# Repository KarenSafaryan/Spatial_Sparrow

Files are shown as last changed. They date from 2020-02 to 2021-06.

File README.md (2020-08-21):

# SpatialSparrow

Multimodal rate discriminaton behavioral task for mice.

## Description of the setup

This should show a labeled picture of the setup. 

## Data saving and automatic copy

This should say what gets saved where and what is automatically copied and when. 

The TouchShaker teensy module reports lick and handle touch times, these get communicated and logged by Bpod.

### SessionData.RawEvents

Event list correspondence :

| TouchShaker byte | Event |
|---|---|
| TouchShaker1_1 | left_spout_touch |
| TouchShaker1_2 | right_spout_touch |
| TouchShaker1_3 | left_spout_release |
| TouchShaker1_4 | right_spout_release |
| TouchShaker1_5 | left_handle_touch |
| TouchShaker1_6 | right_handle_touch |
| TouchShaker1_7 | both_handle_touch |
| TouchShaker1_8 | left_handle_release |
| TouchShaker1_9 | right_handle_release |
| TouchShaker1_14 | acknowledge |
| TouchShaker1_15 | error |

State list correspondence:

## Settings and description

Settings can be set from Bpod (mat files in Bpod Local/Settings).
Default settings are in SpatialSparrow.m

Settings for `training control`:

| Setting | Default | Description |
|---|---|---|
| SubjectName | | Name of the mouse |
| RewardedModality | AudioVisual |'Vision', 'Audio', Somatossensory, 'AudioVisual', 'Mixed' |
| leftRewardVolume | 2 ul | Amount of water per left reward |
| rightRewardVolume | 2 ul | Amount of water per right reward |
| AutoReward | OFF | Pre-load rewarded spout |
| TrainingMode | OFF | Move spouts to the correct side |
| autoRewardVision | 1 | Fraction of self-performed trials (Vision) |
| autoRewardAudio | 1 | Fraction of self-performed trials (Auditory) |
| autoRewardPiezo | 1 | Fraction of self-performed trials (Somatossensory) |
| autoRewardMixed | 1 | Fraction of self-performed trials (Mixed) |
| LeverSound | true | Play a sound when the mouse touches the handles |
| RegularStim | false | Produce regular stimuli sequences |
| biasSeqLength | 3 | nr of trials on one side after which the oposite side is switched with 50% probability |

Settings for `trial timing` :

| Setting | Default | Description |
|---|---|---|
| preStimDelay | 1 (s) | time on handle before stimuli presentation |
| StimDuration | 1 (s) | duration of the stimulus |
| happyTime | 0.5 (s) | duration of the last state (gives time to collect reward) |
| varStimDur | 0 (s) | variable stim duration (StimDuration + varStimDur) is the actual stim duration |
| optoDur | 0.5 (s) | duration of the optogenetics stimuli |
| optoRmp | 0.2 (s) | duration of the optogenetics ramp down (optoDur = 0.5 and optoRamp = 0.2 makes a 500ms stimulus that ramps down after 300ms) ??????? |
| minITI | 1 (s) | min inter trial interval (additional) |
| maxITI | 2 (s) | max inter trial interval (additional) |
| ITIlambda | 10 (AU) | bariability between minITI and maxITI. High lambda -> closer to minITI |
| WaitingTime | 1 (s) | minimum waiting time before a response can be made, early licks are ignored |
| TimeToChoose | 3 (s) | how long to wait for choice report |
| TimeToConfirm | 0.5 (s) | how long to wait for a 2nd (confirmation) lick |
| Timeout | 3 (s) | timeout to punish wrong responses |
| LeverWait | 10 (s) | time to wait for handle grasp |
| MoveLever | TRUE | move levers or not (set to FALSE during habituation)|
| UseBothLevers | FALSE | Whether both handles need to be touched to initiate trials |
| WaitBeforeLever | 1 (s) | Wait time before handles are moved in after trial onset|

Settings for `stimuli parameters` :

| Setting | Default | Description |
|---|---|---|
| TargRate  | 10 (Hz) | Rate of the target sequence |
| ProbRight  | 0.5 | Fraction of targets on the right |
| DistFractions  | 0  | Distractor pulses (fraction of the target sequence). Can be a scalar [0-1] or a vector |
| DistProb  | 0  | Probability of presenting a distractor |
| TestModality  | 0  | Modality to be used with discrimination (1=vis, 2=aud, 4=ss). Zero is inactive. Other values are detection only |
| BinSize  | 50 (ms) | Stimuli refractory period (min interval between pulses) |
| StimCoherence  | TRUE | Determines whether multisensory stimuli are correlated | 
| UseNoise  | FALSE | Use noise burst (TRUE) of clicks (FALSE) as auditory stimuli |
| varStimOn  | [0 0.125 0.25] (s) | Variable onset time for stimulus after lever grab in s. This can be a vector of values. Have to be 0 and higher. |
| StimGap  | 0 (s) | Duration of the gap in the middle of stimulus presentation in s; if >0 the stim duration is of stimDuration*2 + stimGap long |
| DecisionGap  | [0.3 1.5] (s) | Range of the interval between the stimulus and the decision period |
| BeepDuration  | 20 (ms) | Beep (auditory) duration |
| StimLoudness  | 0.5 | Strength of auditory stimuli |
| FlashDuration  | 20 (ms) | Flash (visual) duration |
| StimBrightness  | 20  | Brightness of flashes. Multiplier of the base frequency, default is 100Hz (????) |
| BuzzDuration  | 20 (ms) | Buzz (somatossensory) duration |
| BuzzStrength  | 1  | Strength of buzzes |
| ProbAudio  | 0  | Probability of presenting an auditory-only trial (for multimodal) |
| ProbVisual  | 0  | Probability of presenting a visual-only trial (for multimodal) |
| ProbPiezo  | 0  | Probability of presenting a somatossensory-only trial (for multimodal) |
| sRate  | 20000  | Sampling rate of the AnalogOutput module |
| PunishSoundDur  | 0 (s)  | Duration of the white noise punishment sound |
| optoProb  | 0  | Fraction of optogenetics trials |
| optoTimes  | Stimulus/Delay | Part of the trial where optogenetic stimulus should be presented |
| optoRight  | 0.5  | Probability for occurence of an optogenetic stimulus on the right |
| optoBoth  | 1  | Probability for occurence of an optogenetic stimulus on both sides. This comes after determining a single HS target ??? |
| optoPower  | 5  | Fraction of optogenetics stimuli |

Settings for `hardware control and sync` :

| Setting | Default | Description |
|---|---|---|
| SpoutSpeed | 25 (ms) | Duration of spout movement |
| rMaxSpoutIn | 30 | Right spout inner position (value between 0 and 100) |
| lMaxSpoutIn | 30 | Left spout outer position (value between 0 and 100) |
| spoutOffset | 10 | Distance from inner spout position |
| lOuterLim | 3.5 | Left spout outer position (value between 0 and 100) |
| LeverSpeed | 150 (ms) | Duration of handle movement (ms) |
| LeverIn | 20 | Inner position of the handles |
| LeverOut | 0 | Position of handle out of reach |
| TouchThresh| 5 (SDUs) | Threshold for capacitive touch lines |
| WaitForCam  | false  | Trials wait for a camera trigger to start. |

To check: rInnerLim, lInnerLim, rOuterLim, lOuterLim

Settings for `paths and data copy` :
| Setting | Default | Description |
|---|---|---|
| widefieldPath | ... | path to widefield data on server |
| serverPath |  ... | path to behavioral data on server |
| videoDrive | C: | path to behavioral data on server |
| bonsaiEXE | ... | path to bonsai.exe  |
| bonsaiParadim | ... | path to the bonsai workflow ('' to skip bonsai)  |
| labcamsAddress | localhost:9999 | address to connect to labcams for video acquisition (leave empty to skip) |
| wavePort | COM18 | COM port of the AnalogOutput Module |

`Plot` settings:
| Variable | Default | Description |
|---|---|---|
| PerformanceSwitch| Performed | Show performance over all trials or only self-performed trials |
| DoFit| false | Show curve fitting in the performance plot |
| modSelector| Combined | Which data to show in the performance plot |

Operational variables:
| Variable | Default | Description |
|---|---|---|
| SaveSettings | false | Saves the current settings |
| AdjustSpouts | 0 | Pause for spout adjustment |
| StartTime | ? | Start time of the current session |
| cTrial |  | Number of the current trial |
| runTime |  | Duration of the current session |
| servoPos | [0 0] | position of left and right spout, relative to their inner limit. these values will be changed by anti-bias correction to correct spout position |

## Instalation and build instructions

Clone the repository to Bpod Local/Protocols. If you make changes; create a branch and remember to commit changes regularly.

Build instructions coming here soon.

### Video

There are 2 options for recording video with SpatialSparrow: using [Bonsai](https://bonsai-rx.org/introduction) or using [labcams](https://bitbucket.org/jpcouto/labcams). This readme should show you how to sync the cameras to the BPod (work in progress).

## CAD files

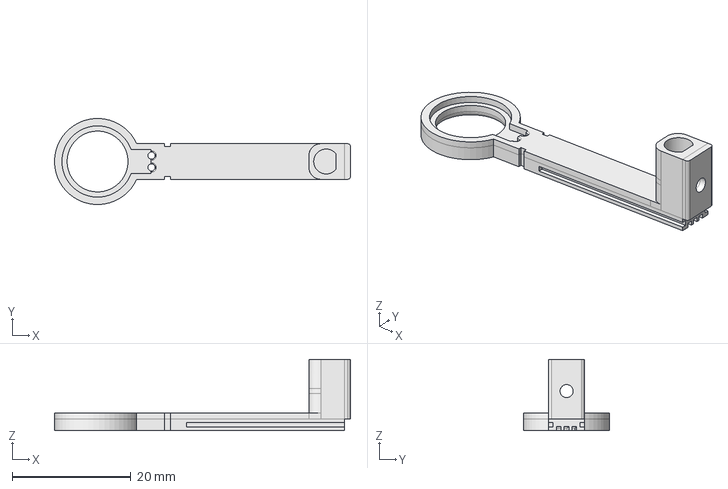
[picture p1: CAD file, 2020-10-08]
parts/freecad/handle_stepper.FCStd
49.9 x 14.5 x 12.0 mm

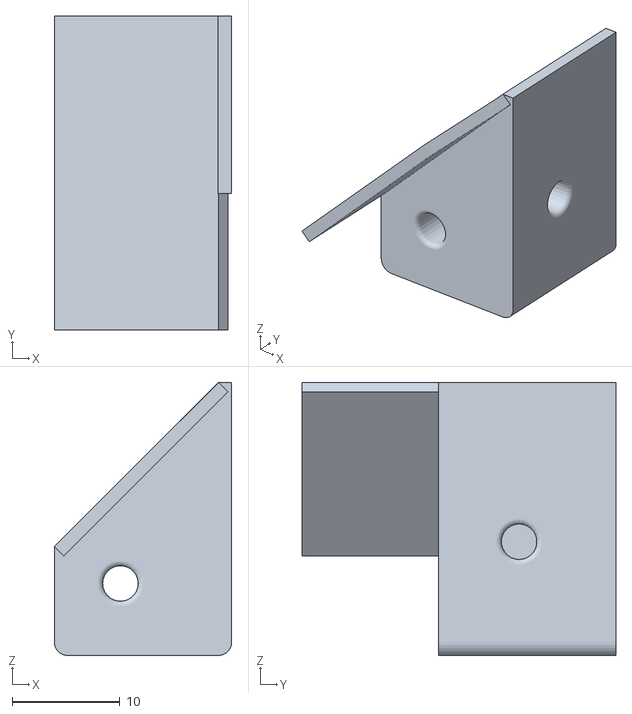
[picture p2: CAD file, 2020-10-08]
parts/stl/01_mirror_holder_45.stl
16.5 x 29.2 x 25.4

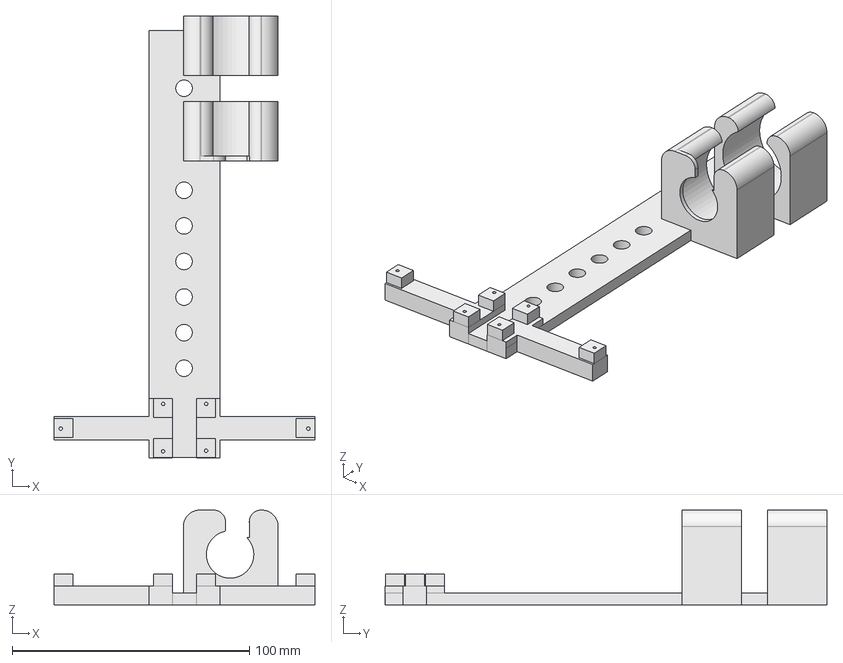
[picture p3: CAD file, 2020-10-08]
parts/freecad/water_valves_external.FCStd
110.0 x 186.1 x 40.0 mm

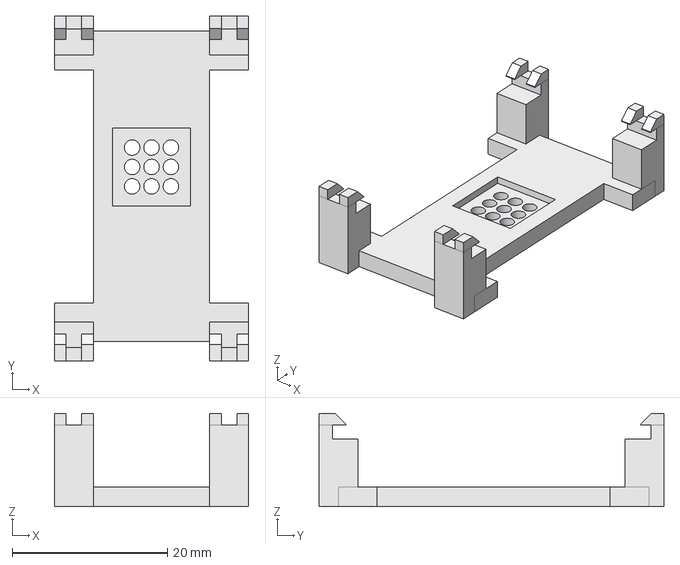
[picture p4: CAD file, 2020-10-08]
parts/freecad/LED_panel_holder.FCStd
25.0 x 44.4 x 12.0 mm

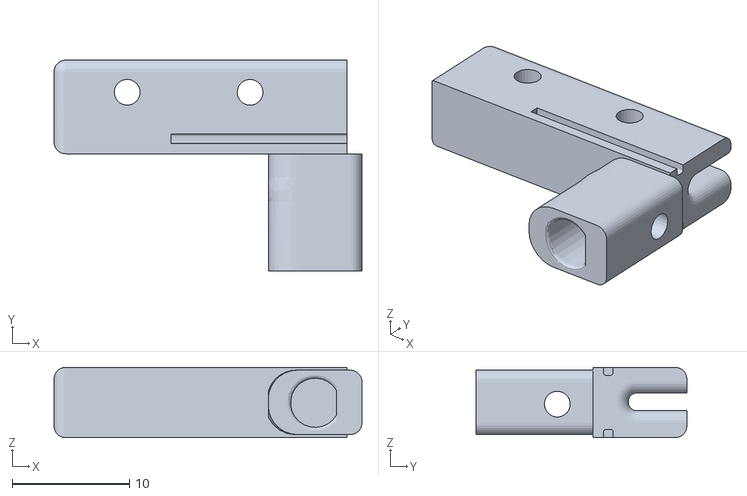
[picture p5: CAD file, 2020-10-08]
parts/stl/02_spout_holder.stl
26.3 x 18.0 x 6.00

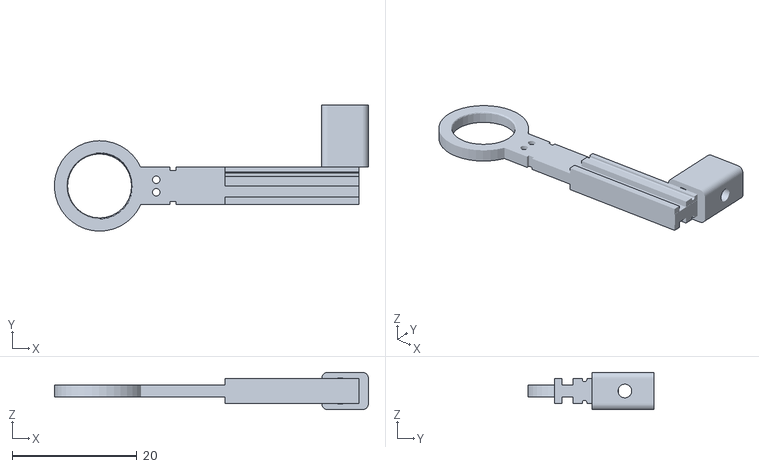
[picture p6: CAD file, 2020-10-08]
parts/stl/02_handle_rotated_flipped.stl
50.3 x 20.2 x 6.00

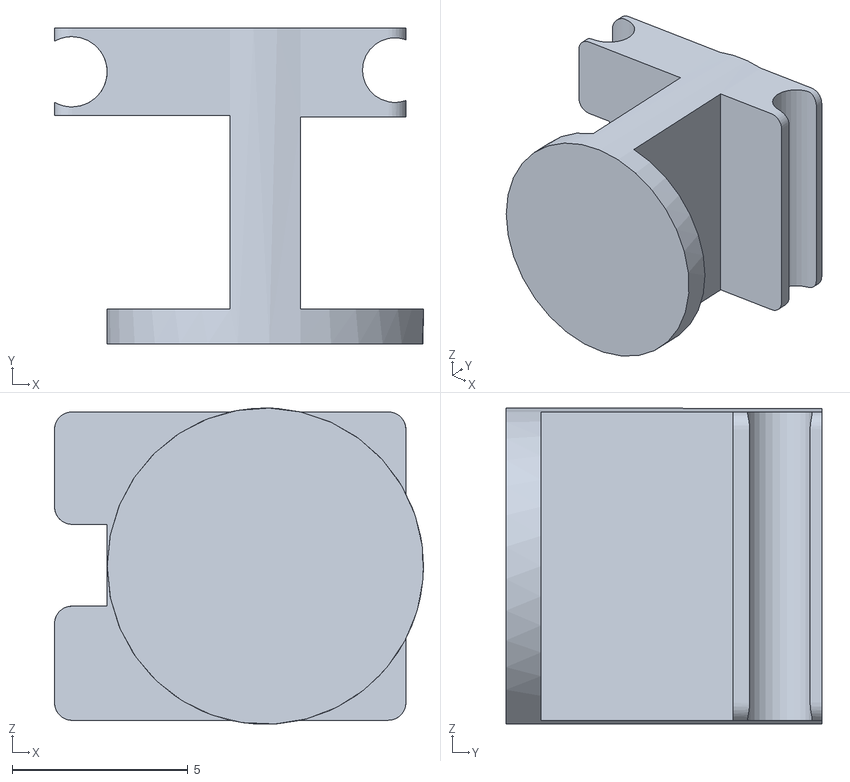
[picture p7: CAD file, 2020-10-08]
parts/stl/02_handle.stl
10.5 x 9.00 x 8.99

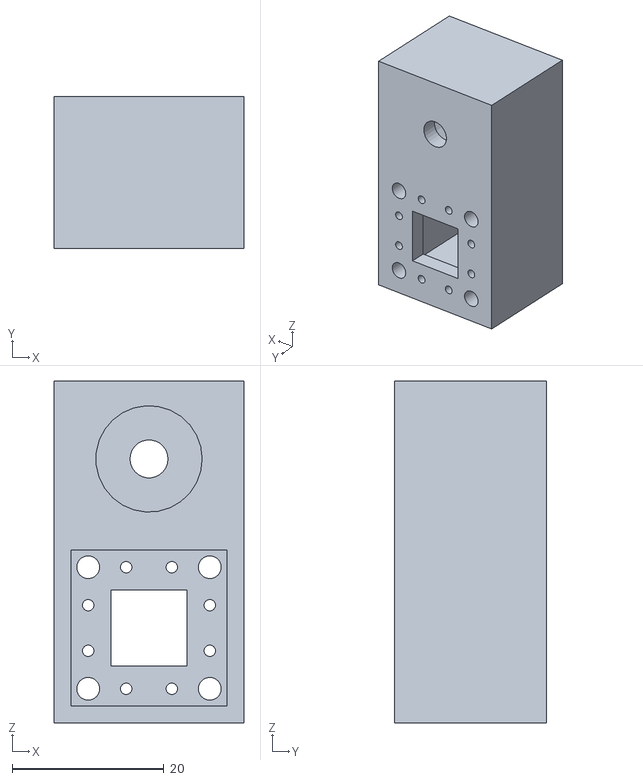
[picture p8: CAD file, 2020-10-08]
parts/stl/02_handle_stepper.stl
25.0 x 20.0 x 45.0

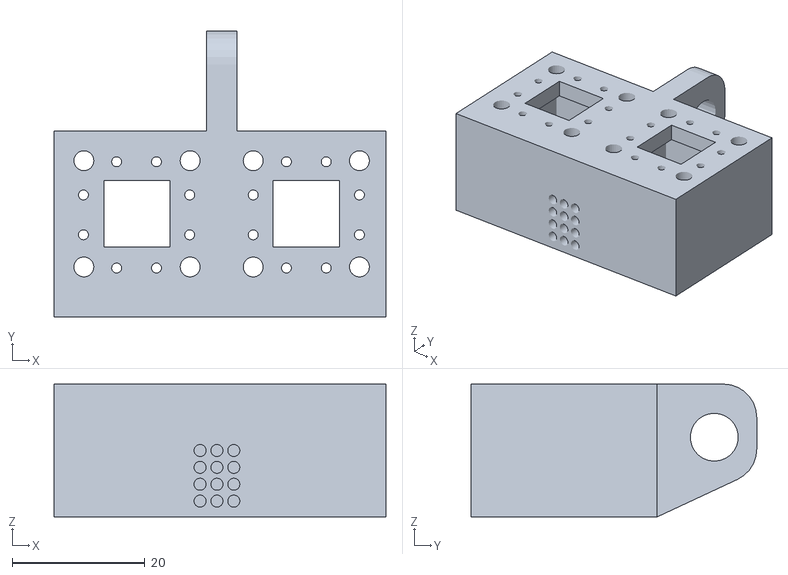
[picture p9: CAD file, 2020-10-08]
parts/stl/01_spout_steppers_holder.stl
50.0 x 43.0 x 20.0

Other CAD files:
parts/stl/01_water_valves_external.stl
parts/freecad/spout_holder.FCStd
parts/freecad/handle_stepper_flipped.FCStd
parts/stl/02_handle_holder.stl

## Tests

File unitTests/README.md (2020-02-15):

+++ Unit tests for the Spatial Sparrow behavioral paradigm

++++ Teensy

     - *Move stepper motor* - tests that the stepper motors are working

     - *Bar graph LED* - tests a teensy LED bar graph 

++++ MATLAB

     - *test_ao.m* - test the bpod analog output module

     - *test_steppers.m* - move and test the spouts and handles

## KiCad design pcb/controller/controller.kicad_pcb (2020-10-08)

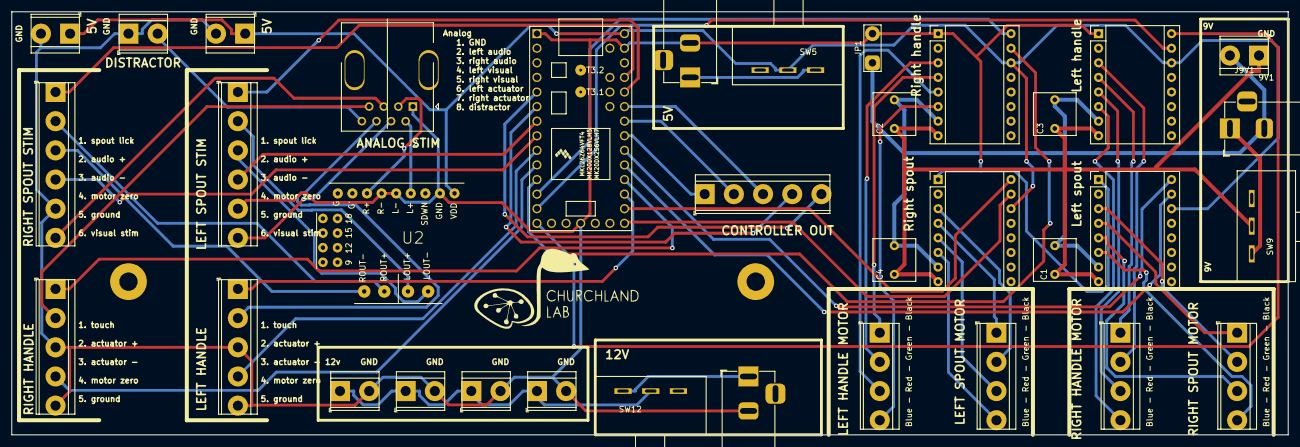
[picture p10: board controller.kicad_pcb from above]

Board: 2 copper layers, 222.2 x 73.7 mm, 37 parts (0 on the bottom side), 56 nets.

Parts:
5V1: 5V; BarrelJack_Horizontal
9V1: 9V; BarrelJack_Horizontal
12V1: 12V; BarrelJack_Horizontal
C1, C2, C3, C4: 100 uF; C_Rect_L7.2mm_W7.2mm_P5.00mm_FKS2_FKP2_MKS2_MKP2
HandleL-ToMotor1: Screw_Terminal_01x04; TerminalBlock_TE_282825-4_1x04_P5.08mm_Horizontal
HandleR-ToMotor1: Screw_Terminal_01x04; TerminalBlock_TE_282825-4_1x04_P5.08mm_Horizontal
J2: RJ45; RJ45_sparkfun
J5V1, J5V2, J9V1, J12V1, J12V2, J12V3, J12V4: Screw_Terminal_01x02; TerminalBlock_TE_282825-2_1x02_P5.08mm_Horizontal
JP1: gnd jumper; TestPoint_2Pads_Pitch5.08mm_Drill1.3mm
MC-LeverL1: Pololu_Breakout_DRV8825; Pololu_Breakout-16_15.2x20.3mm
MC-LeverR1: Pololu_Breakout_DRV8825; Pololu_Breakout-16_15.2x20.3mm
MC-SpoutL1: Pololu_Breakout_DRV8825; Pololu_Breakout-16_15.2x20.3mm
MC-SpoutR1: Pololu_Breakout_DRV8825; Pololu_Breakout-16_15.2x20.3mm
SW5: SW5V; SW_L102021ML04Q
SW9: SW9V; SW_L102021ML04Q
SW12: SW12V; SW_L102021ML04Q
SoundVisionL1: Screw_Terminal_01x06; TerminalBlock_TE_282825-6_1x06_P5.08mm_Horizontal
SoundVisionR1: Screw_Terminal_01x06; TerminalBlock_TE_282825-6_1x06_P5.08mm_Horizontal
SpoutL-ToMotor1: Screw_Terminal_01x04; TerminalBlock_TE_282825-4_1x04_P5.08mm_Horizontal
SpoutR-ToMotor1: Screw_Terminal_01x04; TerminalBlock_TE_282825-4_1x04_P5.08mm_Horizontal
ToHandleL1: Screw_Terminal_01x05; TerminalBlock_TE_282825-5_1x05_P5.08mm_Horizontal
ToHandleR1: Screw_Terminal_01x05; TerminalBlock_TE_282825-5_1x05_P5.08mm_Horizontal
U1: Teensy3.2; Teensy30_31_32_LC
U2: MAX98306
distractor1: Screw_Terminal_01x02; TerminalBlock_TE_282825-2_1x02_P5.08mm_Horizontal
mount1, mount2: MountingHole_3.2mm_M3_Pad
sync_trigger_out1: Screw_Terminal_01x05; TerminalBlock_TE_282825-5_1x05_P5.08mm_Horizontal

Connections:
+5V: J5V1.1, J5V2.1, MC-LeverL1.14, MC-LeverR1.14, MC-SpoutL1.14, MC-SpoutR1.14, SW5.2, U1.33, U2.1
+9V: C1.1, C2.1, C3.1, C4.1, J9V1.1, MC-LeverL1.8, MC-LeverR1.8, MC-SpoutL1.8, MC-SpoutR1.8, SW9.2
+12V: J12V1.1, J12V2.1, J12V3.1, J12V4.1, SW12.2
GND: 5V1.2, 12V1.2, J2.1, J5V1.2, J5V2.2, J12V1.2, J12V2.2, J12V3.2, J12V4.2, JP1.2, MC-LeverL1.1, MC-LeverR1.1, MC-SpoutL1.1, MC-SpoutR1.1, SoundVisionL1.5, SoundVisionR1.5, ToHandleL1.3, ToHandleL1.5, ToHandleR1.3, ToHandleR1.5, U1.1, U1.17, U1.32, U2.2, U2.5, U2.6, distractor1.1
GND1: 9V1.2, C1.2, C2.2, C3.2, C4.2, J9V1.2, JP1.1, MC-LeverL1.7, MC-LeverR1.7, MC-SpoutL1.7, MC-SpoutR1.7
unnamed: 5V1.1, SW5.1
unnamed: 9V1.1, SW9.1
unnamed: 12V1.1, SW12.1
unnamed: HandleL-ToMotor1.1, MC-LeverL1.4
unnamed: HandleL-ToMotor1.2, MC-LeverL1.3
unnamed: HandleL-ToMotor1.3, MC-LeverL1.5
unnamed: HandleL-ToMotor1.4, MC-LeverL1.6
unnamed: HandleR-ToMotor1.1, MC-LeverR1.4
unnamed: HandleR-ToMotor1.2, MC-LeverR1.3
unnamed: HandleR-ToMotor1.3, MC-LeverR1.5
unnamed: HandleR-ToMotor1.4, MC-LeverR1.6
unnamed: J2.2, U2.4
unnamed: J2.3, U2.7
unnamed: J2.4, SoundVisionL1.6
unnamed: J2.5, SoundVisionR1.6
unnamed: J2.6, ToHandleL1.2
unnamed: J2.7, ToHandleR1.2
unnamed: J2.8, distractor1.2
unnamed: MC-LeverL1.15, U1.11
unnamed: MC-LeverL1.16, U1.12
unnamed: MC-LeverR1.15, U1.13
unnamed: MC-LeverR1.16, U1.14
unnamed: MC-SpoutL1.3, SpoutL-ToMotor1.2
unnamed: MC-SpoutL1.4, SpoutL-ToMotor1.1
unnamed: MC-SpoutL1.5, SpoutL-ToMotor1.3
unnamed: MC-SpoutL1.6, SpoutL-ToMotor1.4
unnamed: MC-SpoutL1.15, U1.20
unnamed: MC-SpoutL1.16, U1.21
unnamed: MC-SpoutR1.3, SpoutR-ToMotor1.2
unnamed: MC-SpoutR1.4, SpoutR-ToMotor1.1
unnamed: MC-SpoutR1.5, SpoutR-ToMotor1.3
unnamed: MC-SpoutR1.6, SpoutR-ToMotor1.4
unnamed: MC-SpoutR1.15, U1.24
unnamed: MC-SpoutR1.16, U1.25
unnamed: SoundVisionL1.1, U1.29
unnamed: SoundVisionL1.2, U2.11
unnamed: SoundVisionL1.3, U2.10
unnamed: SoundVisionL1.4, U1.7
unnamed: SoundVisionR1.1, U1.30
unnamed: SoundVisionR1.2, U2.12
unnamed: SoundVisionR1.3, U2.13
unnamed: SoundVisionR1.4, U1.8
unnamed: ToHandleL1.1, U1.22
unnamed: ToHandleL1.4, U1.9
unnamed: ToHandleR1.1, U1.23
unnamed: ToHandleR1.4, U1.10
unnamed: U1.5, sync_trigger_out1.5
unnamed: U1.6, sync_trigger_out1.4
unnamed: U1.26, sync_trigger_out1.1
unnamed: U1.27, sync_trigger_out1.2
unnamed: U1.28, sync_trigger_out1.3

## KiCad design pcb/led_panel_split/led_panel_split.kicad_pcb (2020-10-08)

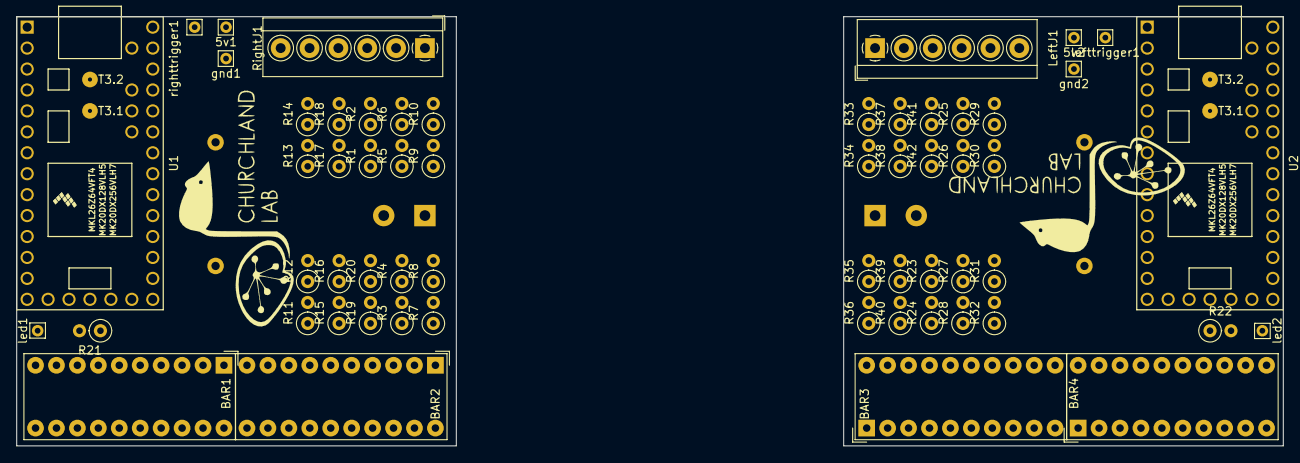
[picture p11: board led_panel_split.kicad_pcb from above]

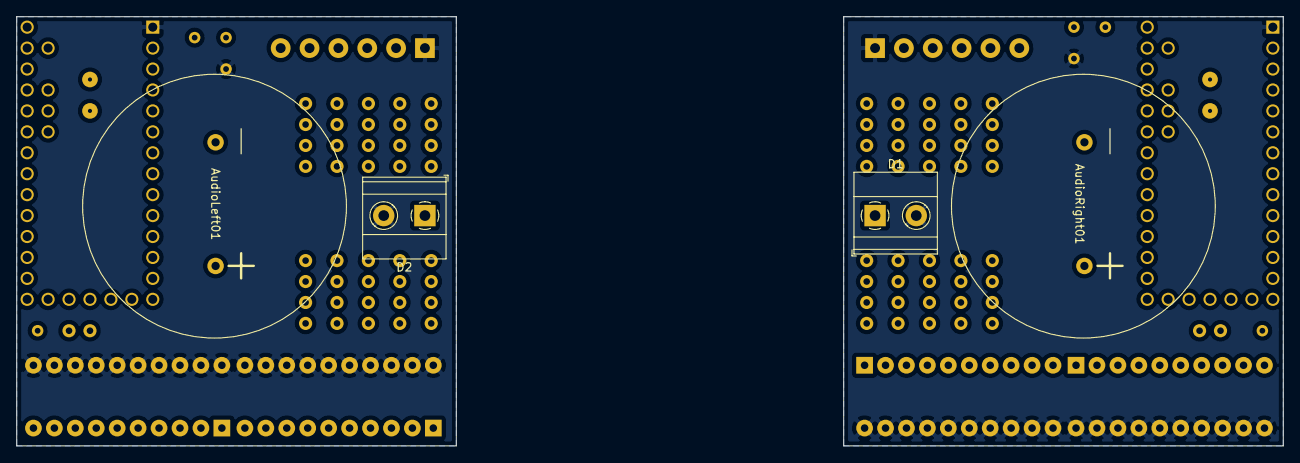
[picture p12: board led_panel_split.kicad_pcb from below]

Board: 2 copper layers, 153.7 x 52.1 mm, 64 parts (4 on the bottom side), 92 nets, no tracks yet.

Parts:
5v1, 5v2: 5V; Pin_D0.7mm_L6.5mm_W1.8mm_FlatFork
AudioLeft01: Audio left; speaker
AudioRight01: Audio right; speaker
BAR1, BAR2, BAR3, BAR4: HDSP-4830_2; HDSP-4830
D1, D2: LED; TerminalBlock_Phoenix_MKDS-1,5-2_1x02_P5.00mm_Horizontal
G1, G2: LOGO; churchland_lab_logo
LeftJ1: Left screw terminal; TerminalBlock_4Ucon_1x06_P3.50mm_Horizontal
R1, R2, R3, R4, R5, R6, R7, R8, R9, R10, R11, R12, R13, R14, R15, R16, R17, R18, R19, R20, R21, R22, R23, R24, R25, R26, R27, R28, R29, R30, R31, R32, R33, R34, R35, R36, R37, R38, R39, R40, R41, R42: R; R_Axial_DIN0207_L6.3mm_D2.5mm_P2.54mm_Vertical
RightJ1: Right screw terminal; TerminalBlock_4Ucon_1x06_P3.50mm_Horizontal
U1, U2: Teensy3.2; Teensy30_31_32_LC
gnd1, gnd2: GND; Pin_D0.7mm_L6.5mm_W1.8mm_FlatFork
led1: LED1 test; Pin_D0.7mm_L6.5mm_W1.8mm_FlatFork
led2: LED2 test; Pin_D0.7mm_L6.5mm_W1.8mm_FlatFork
lefttrigger1: left trigger; Pin_D0.7mm_L6.5mm_W1.8mm_FlatFork
righttrigger1: right trigger; Pin_D0.7mm_L6.5mm_W1.8mm_FlatFork

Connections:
+5V: 5v1.1, 5v2.1, LeftJ1.2, RightJ1.2, U1.33, U2.33
GND: BAR1.11, BAR1.12, BAR1.13, BAR1.14, BAR1.15, BAR1.16, BAR1.17, BAR1.18, BAR1.19, BAR1.20, BAR2.11, BAR2.12, BAR2.13, BAR2.14, BAR2.15, BAR2.16, BAR2.17, BAR2.18, BAR2.19, BAR2.20, BAR3.11, BAR3.12, BAR3.13, BAR3.14, BAR3.15, BAR3.16, BAR3.17, BAR3.18, BAR3.19, BAR3.20, BAR4.11, BAR4.12, BAR4.13, BAR4.14, BAR4.15, BAR4.16, BAR4.17, BAR4.18, BAR4.19, BAR4.20, D1.2, D2.2, LeftJ1.1, RightJ1.1, U1.1, U2.1, gnd1.1, gnd2.1
unnamed: AudioLeft01.1, LeftJ1.5
unnamed: AudioLeft01.2, LeftJ1.6
unnamed: AudioRight01.1, RightJ1.5
unnamed: AudioRight01.2, RightJ1.6
unnamed: BAR1.1, R20.2
unnamed: BAR1.2, R19.2
unnamed: BAR1.3, R18.2
unnamed: BAR1.4, R17.2
unnamed: BAR1.5, R16.2
unnamed: BAR1.6, R15.2
unnamed: BAR1.7, R14.2
unnamed: BAR1.8, R13.2
unnamed: BAR1.9, R12.2
unnamed: BAR1.10, R11.2
unnamed: BAR2.1, R10.2
unnamed: BAR2.2, R9.2
unnamed: BAR2.3, R8.2
unnamed: BAR2.4, R7.2
unnamed: BAR2.5, R6.2
unnamed: BAR2.6, R5.2
unnamed: BAR2.7, R4.2
unnamed: BAR2.8, R3.2
unnamed: BAR2.9, R2.2
unnamed: BAR2.10, R1.2
unnamed: BAR3.1, R33.2
unnamed: BAR3.2, R34.2
unnamed: BAR3.3, R35.2
unnamed: BAR3.4, R36.2
unnamed: BAR3.5, R37.2
unnamed: BAR3.6, R38.2
unnamed: BAR3.7, R39.2
unnamed: BAR3.8, R40.2
unnamed: BAR3.9, R41.2
unnamed: BAR3.10, R42.2
unnamed: BAR4.1, R23.2
unnamed: BAR4.2, R24.2
unnamed: BAR4.3, R25.2
unnamed: BAR4.4, R26.2
unnamed: BAR4.5, R27.2
unnamed: BAR4.6, R28.2
unnamed: BAR4.7, R29.2
unnamed: BAR4.8, R30.2
unnamed: BAR4.9, R31.2
unnamed: BAR4.10, R32.2
unnamed: D1.1, R21.2
unnamed: D2.1, R22.2
unnamed: LeftJ1.3, R22.1, led2.1
unnamed: LeftJ1.4, U2.30, lefttrigger1.1
unnamed: R1.1, U1.12
unnamed: R2.1, U1.13
unnamed: R3.1, U1.14
unnamed: R4.1, U1.20
unnamed: R5.1, U1.21
unnamed: R6.1, U1.22
unnamed: R7.1, U1.23
unnamed: R8.1, U1.24
unnamed: R9.1, U1.25
unnamed: R10.1, U1.26
unnamed: R11.1, U1.2
unnamed: R12.1, U1.3
unnamed: R13.1, U1.4
unnamed: R14.1, U1.5
unnamed: R15.1, U1.6
unnamed: R16.1, U1.7
unnamed: R17.1, U1.8
unnamed: R18.1, U1.9
unnamed: R19.1, U1.10
unnamed: R20.1, U1.11
unnamed: R21.1, RightJ1.3, led1.1
unnamed: R23.1, U2.11
unnamed: R24.1, U2.10
unnamed: R25.1, U2.9
unnamed: R26.1, U2.8
unnamed: R27.1, U2.7
unnamed: R28.1, U2.6
unnamed: R29.1, U2.5
unnamed: R30.1, U2.4
unnamed: R31.1, U2.3
unnamed: R32.1, U2.2
unnamed: R33.1, U2.26
unnamed: R34.1, U2.25
unnamed: R35.1, U2.24
unnamed: R36.1, U2.23
unnamed: R37.1, U2.22
unnamed: R38.1, U2.21
unnamed: R39.1, U2.20
unnamed: R40.1, U2.14
unnamed: R41.1, U2.13
unnamed: R42.1, U2.12
unnamed: RightJ1.4, U1.30, righttrigger1.1

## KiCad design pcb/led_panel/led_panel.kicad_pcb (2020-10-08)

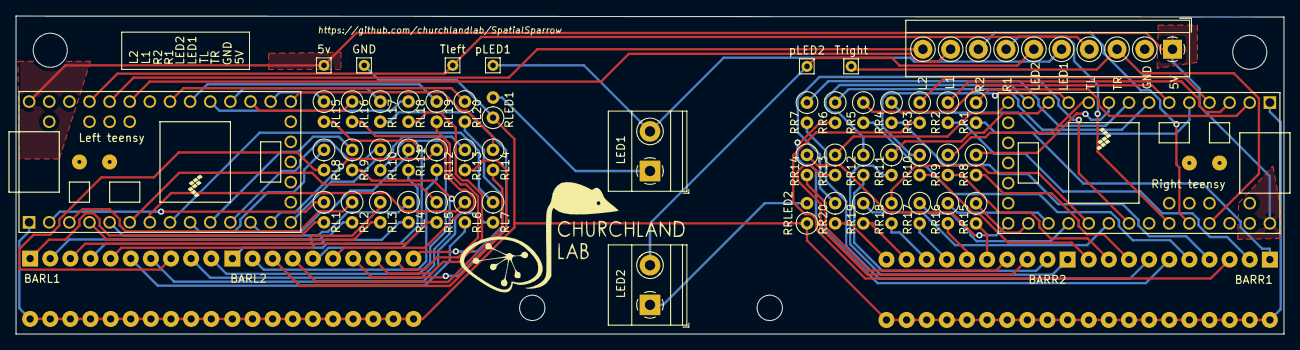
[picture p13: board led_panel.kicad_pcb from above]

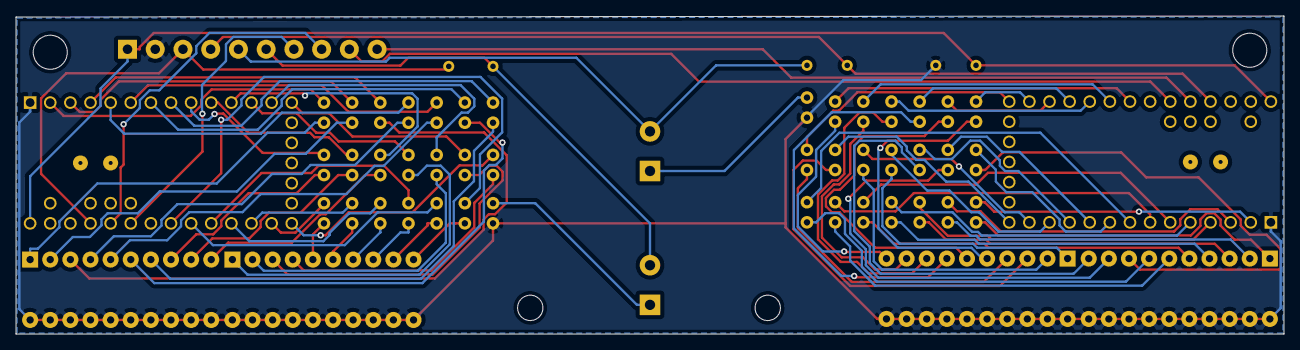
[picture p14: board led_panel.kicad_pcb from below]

Board: 2 copper layers, 160.0 x 40.1 mm, 61 parts (2 on the bottom side), 92 nets.

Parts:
5v: 5V; Pin_D0.7mm_L6.5mm_W1.8mm_FlatFork
BARL1, BARL2: HDSP-4830_2; HDSP-4830
BARR1, BARR2: HDSP-4830_2; HDSP-4830
GND: GND; Pin_D0.7mm_L6.5mm_W1.8mm_FlatFork
LED1, LED2: LED; TerminalBlock_Phoenix_MKDS-1,5-2_1x02_P5.00mm_Horizontal
Left teensy: Teensy3.2; Teensy30_31_32_LC
M3_1, M3_2: MountingHole_3.2mm_M3
M4_1, M4_2: MountingHole_4.3mm_M4
RL1, RL2, RL3, RL4, RL5, RL6, RL7, RL8, RL9, RL10, RL11, RL12, RL13, RL14, RL15, RL16, RL17, RL18, RL19, RL20: R; R_Axial_DIN0207_L6.3mm_D2.5mm_P2.54mm_Vertical
RLED1: R; R_Axial_DIN0207_L6.3mm_D2.5mm_P2.54mm_Vertical
RR1, RR2, RR3, RR4, RR5, RR6, RR7, RR8, RR9, RR10, RR11, RR12, RR13, RR14, RR15, RR16, RR17, RR18, RR19, RR20: R; R_Axial_DIN0207_L6.3mm_D2.5mm_P2.54mm_Vertical
RRLED2: R; R_Axial_DIN0207_L6.3mm_D2.5mm_P2.54mm_Vertical
Right teensy: Teensy3.2; Teensy30_31_32_LC
Tleft: T right; Pin_D0.7mm_L6.5mm_W1.8mm_FlatFork
Tright: T right; Pin_D0.7mm_L6.5mm_W1.8mm_FlatFork
pLED1: LED1; Pin_D0.7mm_L6.5mm_W1.8mm_FlatFork
pLED2: LED2; Pin_D0.7mm_L6.5mm_W1.8mm_FlatFork
terminal: Screw_Terminal_01x10; TerminalBlock_4Ucon_1x10_P3.50mm_Horizontal

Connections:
+5V: 5v.1, Left teensy.33, Right teensy.33, terminal.1
GND: BARL1.11, BARL1.12, BARL1.13, BARL1.14, BARL1.15, BARL1.16, BARL1.17, BARL1.18, BARL1.19, BARL1.20, BARL2.11, BARL2.12, BARL2.13, BARL2.14, BARL2.15, BARL2.16, BARL2.17, BARL2.18, BARL2.19, BARL2.20, BARR1.11, BARR1.12, BARR1.13, BARR1.14, BARR1.15, BARR1.16, BARR1.17, BARR1.18, BARR1.19, BARR1.20, BARR2.11, BARR2.12, BARR2.13, BARR2.14, BARR2.15, BARR2.16, BARR2.17, BARR2.18, BARR2.19, BARR2.20, GND.1, Left teensy.1, RLED1.1, RRLED2.1, Right teensy.1, terminal.2
unnamed: BARL1.1, RL1.2
unnamed: BARL1.2, RL2.2
unnamed: BARL1.3, RL3.2
unnamed: BARL1.4, RL4.2
unnamed: BARL1.5, RL5.2
unnamed: BARL1.6, RL6.2
unnamed: BARL1.7, RL7.2
unnamed: BARL1.8, RL8.2
unnamed: BARL1.9, RL9.2
unnamed: BARL1.10, RL10.2
unnamed: BARL2.1, RL11.2
unnamed: BARL2.2, RL12.2
unnamed: BARL2.3, RL13.2
unnamed: BARL2.4, RL14.2
unnamed: BARL2.5, RL15.2
unnamed: BARL2.6, RL16.2
unnamed: BARL2.7, RL17.2
unnamed: BARL2.8, RL18.2
unnamed: BARL2.9, RL19.2
unnamed: BARL2.10, RL20.2
unnamed: BARR1.1, RR1.2
unnamed: BARR1.2, RR2.2
unnamed: BARR1.3, RR3.2
unnamed: BARR1.4, RR4.2
unnamed: BARR1.5, RR5.2
unnamed: BARR1.6, RR6.2
unnamed: BARR1.7, RR7.2
unnamed: BARR1.8, RR8.2
unnamed: BARR1.9, RR9.2
unnamed: BARR1.10, RR10.2
unnamed: BARR2.1, RR11.2
unnamed: BARR2.2, RR12.2
unnamed: BARR2.3, RR13.2
unnamed: BARR2.4, RR14.2
unnamed: BARR2.5, RR15.2
unnamed: BARR2.6, RR16.2
unnamed: BARR2.7, RR17.2
unnamed: BARR2.8, RR18.2
unnamed: BARR2.9, RR19.2
unnamed: BARR2.10, RR20.2
unnamed: LED1.1, RLED1.2
unnamed: LED1.2, pLED1.1, terminal.5
unnamed: LED2.1, RRLED2.2
unnamed: LED2.2, pLED2.1, terminal.6
unnamed: Right teensy.30, Tright.1, terminal.3
unnamed: Left teensy.30, Tleft.1, terminal.4
unnamed: Right teensy.28, terminal.7
unnamed: Right teensy.29, terminal.8
unnamed: Left teensy.28, terminal.9
unnamed: Left teensy.29, terminal.10
unnamed: Left teensy.2, RL1.1
unnamed: Left teensy.3, RL2.1
unnamed: Left teensy.4, RL3.1
unnamed: Left teensy.5, RL4.1
unnamed: Left teensy.6, RL5.1
unnamed: Left teensy.7, RL6.1
unnamed: Left teensy.8, RL7.1
unnamed: Left teensy.9, RL8.1
unnamed: Left teensy.10, RL9.1
unnamed: Left teensy.11, RL10.1
unnamed: Left teensy.13, RL12.1
unnamed: Left teensy.14, RL13.1
unnamed: Left teensy.20, RL14.1
unnamed: Left teensy.21, RL15.1
unnamed: Left teensy.22, RL16.1
unnamed: Left teensy.23, RL17.1
unnamed: Left teensy.24, RL18.1
unnamed: Left teensy.25, RL19.1
unnamed: Left teensy.26, RL20.1
unnamed: RR1.1, Right teensy.2
unnamed: RR2.1, Right teensy.3
unnamed: RR3.1, Right teensy.4
unnamed: RR4.1, Right teensy.5
unnamed: RR5.1, Right teensy.6
unnamed: RR6.1, Right teensy.7
unnamed: RR7.1, Right teensy.8
unnamed: RR8.1, Right teensy.9
unnamed: RR9.1, Right teensy.10
unnamed: RR10.1, Right teensy.11
unnamed: RR11.1, Right teensy.12
unnamed: RR12.1, Right teensy.13
unnamed: RR13.1, Right teensy.14
unnamed: RR14.1, Right teensy.20
unnamed: RR15.1, Right teensy.21
unnamed: RR16.1, Right teensy.22
unnamed: RR17.1, Right teensy.23
unnamed: RR18.1, Right teensy.24
unnamed: RR19.1, Right teensy.25
unnamed: RR20.1, Right teensy.26
unnamed: Left teensy.12, RL11.1

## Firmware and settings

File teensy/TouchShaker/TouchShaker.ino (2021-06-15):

#include "Arduino.h"
#include "ArCOM.h"

#define HANDLE_MOTOR_BOTTOM 1
#ifdef HANDLES_MOTOR_BOTTOM
#define LOW_DIR_H HIGH
#define HIGH_DIR_H LOW
#else
#define LOW_DIR_H LOW
#define HIGH_DIR_H HIGH
#endif

#define SPOUT_MOTOR_BOTTOM 1
#ifdef SPOUT_MOTOR_BOTTOM
#define LOW_DIR_S HIGH
#define HIGH_DIR_S LOW
#else
#define LOW_DIR_S LOW
#define HIGH_DIR_S HIGH
#endif


//#define USE_LOAD_CELL 1
#ifdef USE_LOAD_CELL
#include "HX711.h" //This load-cell library can be obtained here http://librarymanager/All#Avia_HX711
#endif
// –--–--–--–--–--–--–--–--–--–--–--–--–--–--–--–--–--–--–--–--–--–--–--–--–--–--–--–--–--–--–--–--–--–--–--–--
// This version includes:
// control two stepper motors to move the sputes
// control two stepper motors to move levers
// reads water spout and lever touches using capacitive sensing.
// serial communication with bpod v2 state machine
// –--–--–--–--–--–--–--–--–--–--–--–--–--–--–--–--–--–--–--–--–--–--–--–--–--–--–--–--–--–--–--–--–--–--–--–--

// Serial-write variables
unsigned long FirmwareVersion = 2;
char moduleName[] = "TouchShaker"; // Name of module for manual override UI and state machine assembler
ArCOM Serial1COM(Serial1); // UART serial port

unsigned long clocker = millis();
unsigned long stimClocker = millis();
unsigned long trialClocker = millis();
int FSMheader = 0;
const int sRateLicks = 5;  // This is the minimum duration of lick events that are send to bpod.
const int sRateLever = 10; // This is the number of ms for outputs to be during levertouch. Signal remains live until 'sRateLever' ms after the last contact.

/* #################################################
  ############## PIN CONFIGURATION ###################
  #################################################### */
// TTL Outputs
#define PIN_STIMTRIG 21 // stimulus trigger that can be switched by serial command 'MAKE_STIMTRIGGER'
#define PIN_TRIALTRIG 4 // trial-start trigger that can be switched by serial command 'MAKE_TRIALTRIGGER'
#define PIN_CAMTIMER 3 // Trigger to synchronize camera acquisition. Sends TTL for 'camTrigDur' with an inter-pulse of 'camTrigRate'.

#ifdef USE_LOAD_CELL
// load cell pins
#define LOADCELL_SCK_PIN  19
#define LOADCELL_DOUT_PIN  20
HX711 scale;
#endif
// Inputs for lick sensors
#define LEVERSENSOR_L 15 // touch line for lever touch
#define LEVERSENSOR_R 16 // touch line for lever touch
#define SPOUTSENSOR_L 22 // touch line for left spout
#define SPOUTSENSOR_R 23 // touch line for right spout
// Pins for stepper - spouts
#define PIN_SPOUTOUT_L 5
#define PIN_SPOUTOUT_R 6
#define PIN_SPOUTSTEP_L 13
#define PIN_SPOUTDIR_L 14
#define PIN_SPOUTSTEP_R 17
#define PIN_SPOUTDIR_R 18
// Pins for stepper - handles
#define PIN_LEVEROUT_L 7
#define PIN_LEVEROUT_R 8
#define PIN_LEVERSTEP_L 9
#define PIN_LEVERDIR_L 10
#define PIN_LEVERSTEP_R 11
#define PIN_LEVERDIR_R 12

/* #################################################
  ########### UART/BPOD COMMUNICATION ################
  #################################################### */
// Byte codes for serial communication
// inputs
#define MODULE_INFO 255 // byte to return module info
#define HWRESET 128
#define START_TRIAL 70 // identifier to start trial, provides limit for wheel motion and servo movement
#define ADJUST_SPOUTES 71 // identifier to change spout positions
#define ADJUST_LEVER 72 // identifier to change lever positions
#define ADJUST_SPOUTSPEED 73 // identifier to change spout servo speed
#define ADJUST_LEVERSPEED 74 // identifier to change lever servo speed
#define ADJUST_TOUCHLEVEL 75 // identifier to re-adjust threshold for touch sensors. Will sample over 1 second of data to infer mean/std of measurements.
#define CHECK_LEVERS 76 // identifier to provide information over which handles are being touched
#define MAKE_STIMTRIGGER 77 // identifier to produce a stimulus trigger
#define MAKE_TRIALTRIGGER 78 // identifier to produce a trial onset trigger
#define INCREASE_SPOUTTHRESH_L 80 // identifier to increase touch threshold for the left spout
#define DECREASE_SPOUTTHRESH_L 81 // identifier to decrease touch threshold for the left spout
#define INCREASE_SPOUTTHRESH_R 82 // identifier to increase touch threshold for the right spout
#define DECREASE_SPOUTTHRESH_R 83 // identifier to decrease touch threshold for the right spout
#define INCREASE_LEVERTHRESH_L 84 // identifier to increase touch threshold for the left LEVER
#define DECREASE_LEVERTHRESH_L 85 // identifier to decrease touch threshold for the left LEVER
#define INCREASE_LEVERTHRESH_R 86 // identifier to increase touch threshold for the right LEVER
#define DECREASE_LEVERTHRESH_R 87 // identifier to decrease touch threshold for the right LEVER
#define SET_TOUCHLEVELS 89
#define GET_TOUCHLEVELS 95 // send the touch thresholds to bpod
#define IS_MOVING 88

#define START_SCALE 91 // identifier to start logging data from the load cell
#define STOP_SCALE 92 // identifier to stop logging data from the load cell
#define SEND_DATA_SCALE 93 // identifier to return data from load cell recording
// outputs
#define LEFT_SPOUT_TOUCH 1 // byte to indicate left spout is being touched
#define RIGHT_SPOUT_TOUCH 2 // byte to indicate right spout is being touched
#define LEFT_SPOUT_RELEASE 3 // byte to indicate left spout was released
#define RIGHT_SPOUT_RELEASE 4 // byte to indicate left spout was released
#define LEFT_HANDLE_TOUCH 5 // byte to indicate left handle is being touched
#define RIGHT_HANDLE_TOUCH 6 // byte to indicate that right handle is being touched
#define BOTH_HANDLES_TOUCH 7 // byte to indicate that both handles are being touched
#define LEFT_HANDLE_RELEASE 8 // byte to indicate left handle was released
#define RIGHT_HANDLE_RELEASE 9 // byte to indicate that right handle was released
#define OK 14 // positive handshake for bpod commands
#define FAIL 15 // negative handshake for bpod commands

// other serial commands during the trial
#define SPOUTS_IN 101 // serial command to move the spouts in
#define SPOUTS_OUT 106 // serial command to move the spouts out
#define LEFT_SPOUT_OUT 102 // serial command to move the left spout out
#define RIGHT_SPOUT_OUT 103 // serial command to move the right spout out
#define LEVER_IN 104 // serial command to move the lever in
#define LEVER_OUT 105 // serial command to move the lever out

/* #################################################
  ##################### VARIABLES ####################
  #################################################### */
// Servo vars
float lServoIn = 10; // position to be reached when spouts are moved in by bpod trigger.
float lServoOut = 0;  // position to be reached when spouts are moved outin by bpod trigger.
float lServoAdjust = 0; // position that is taken when matlab changes spout position via the ADJUST_SPOUTS event.
float lServoCurrent = 0; // current servo position - tracks where the servo currently is.
float rServoIn = 10; // position to be reached when spouts are moved in by bpod trigger.
float rServoOut = 0;  // position to be reached when spouts are moved out by bpod trigger.
float rServoAdjust = 0; // position that is taken when matlab changes spout position via the ADJUST_SPOUTS event.
float rServoCurrent = 0; // current servo position - tracks where the servo currently is.
float leverIn = 10; // inner lever position.
float leverOut = 0; // outer lever position.
float leverAdjust = 0; // lever position via adjust_lever commands.
float leverCurrent = 0; // current lever position

float spoutSpeed = 50000; // duration of the spout movement in us.
float leverSpeed = 50000; // duration of the lever movement in us. this is the time it takes the lever to move from the outer to the inner position or vice versa.
unsigned long lSpoutClocker = micros(); // timer to modulate speed of left spout
unsigned long rSpoutClocker = micros(); // timer to modulate speed of right spout
unsigned long lClocker = micros(); // timer to modulate speed of lever motion
unsigned long touchClocker_L = millis(); // timer to measure duration of lever touch
unsigned long touchClocker_R = millis(); // timer to measure duration of lever touch
int lSpoutInc = 1000; // incremental left spout motion to modulate speed
int rSpoutInc = 1000; // incremental right spout motion to modulate speed
int leverInc = 1000; // time between steps of the handle motor to move at requested speed
int touchChangeInc = 2; // step size when increasing/decreasing touch thresholds

// flags for current servo states. Required to control servo speed
bool stimTrigger = false; // flag to indicate that stim trigger is produced
bool trialTrigger = false; // flag to indicate that trial trigger is produced
bool spoutMoves = false; // flag to indicate that spouts are in motion
bool lSpoutMovesIn = false; // flag to indicate that spout is moving to inward position
bool lSpoutMovesOut = true; // flag to indicate that spout is moving to outward position
bool lSpoutMovesAdjust = false; // flag to indicate that spout is moving to outward position
bool rSpoutMovesIn = false; // flag to indicate that spout is moving to inward position
bool rSpoutMovesOut = true; // flag to indicate that spout is moving to outward position
bool rSpoutMovesAdjust = false; // flag to indicate that spout is moving to outward position
bool leverMoves = false; // flag to indicate that lever is in motion
bool lMovesIn = false; // flag to indicate that lever is moving to inward position
bool lMovesOut = true; // flag to indicate that lever is moving to outward position
bool lMovesAdjust = false; // flag to indicate that lever is moving to outward position
unsigned long spoutClocker_L = millis(); // timer to measure duration of left lick
unsigned long spoutClocker_R = millis(); // timer to measure duration of right lick

// Touch variables
int touchAdjustDur = 2000; // time used to re-adjust touch levels if neccessary. This will infer the mean (in the first hald) and standard deviation (in the second half) of the read-noise to infer decent thresholds for touch.
int touchThresh = 3; // threshold for touch event in standard deviation units.
int touchThreshOffset = 50; // additional offset for touch threshold.
bool touchAdjust = true; // flag to determine values to detect touches. Do this on startup.
float touchData[4]; // current values for the four touch lines (left spout, right spout, left, handle, right handle)
float meanTouchVals[4]; // mean values for the four touch lines (left spout, right spout, left, handle, right handle)
float stdTouchVals[4]; // stand deviation values for the four touch lines (left spout, right spout, left, handle, right handle)
float touchVal = 0; // temporary variable for usb communication
long int sampleCnt[] = {0, 0}; // counter for samples during touch adjustment
unsigned long adjustClocker = millis(); // timer for re-adjustment of touch lines

// Other variables
bool midRead = false;
bool spoutTouch_L = false; // flag to indicate that left spout is touched
bool spoutTouch_R = false; // flag to indicate that right spout is touched
bool leverTouch_L = false; // flag to indicate that left lever is touched
bool leverTouch_R = false; // flag to indicate that right lever is touched
bool leverTouch_BOTH = false; // flag to indicate that both levers are touched
bool findSpoutOut[2] = {true, true}; // flag that stepper motors are being moved out.
bool findLeverOut[2] = {true, true}; // flag that stepper motors are being moved out.
int stepPulse = 10; // duration of stepper pulse in microseconds
int stimDur = 5; // duration of stimulus trigger in ms
int trialDur = 50; // duration of trial trigger in ms
float temp[10]; // temporary variable for general purposes
int camTrigRate = 90; // rate of camera trigger in Hz.

#ifdef USE_LOAD_CELL
unsigned long scaleClocker = millis(); // timer for load-cell measurements
bool readScale = false; // flag to collect data from load-cell
int scaleRate = 10; // duration between samples from load-cell in ms (default is 10ms).
unsigned long scaleCnt = 0; //counter to fill readings into scaleVals
#define SCALE_READS 100 // maximum samples from load-cell per trial. Default duration for readout at 100Hz is 1 minute. decrease from 60000 for memory
long scaleVals[SCALE_READS]; //array for scale readings.
bool scaleWrap = false; // flag that scale reacording was above maximum. In this case, the full scaleVals array and the current scaleCnt is sent to Bpod.
int weight_val = 0;
#endif

unsigned long usbClocker = millis();
int usbRate = 5;
/* #################################################
  ##################### CAMERA TRIGGER ###############
  #################################################### */
// volatile long cameraFramesCounter = 0;

//////////////////////////////////////////////////////////////////////////////////////////////////////////////////////////////////////////////////////////////////////////
void setup() {
  // put your setup code here, to run once:
  Serial1.begin(1312500); //baud rate for UART bpod serial communication
  Serial.begin(9600); // USB baud rate
  //Serial.println("Started spatial sparrow");
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
void loop() {
  // This is the main loop for the teensy
  ///////////////////////////////////////////////////////////////////////////////////////
  // make stim trigger
  if (stimTrigger) {
    if ((millis() - stimClocker) > stimDur) {  // done with stim trigger
      digitalWriteFast(PIN_STIMTRIG, LOW); // set stimulus trigger to low
      stimTrigger = false;
    }
  }

  // make trial trigger
  if (trialTrigger) {
    if ((millis() - trialClocker) > trialDur) {  // done with trial trigger
      digitalWriteFast(PIN_TRIALTRIG, LOW); // set trial trigger to low
      trialTrigger = false;
    }
  }

  ////////////////////////////////////////////////////////////////////////////////////////////////////////////
  // get data from touch pins
  touchData[0] = (touchData[0] * 15 + touchRead(SPOUTSENSOR_L)) / 16;
  touchData[1] = (touchData[1] * 15 + touchRead(SPOUTSENSOR_R)) / 16;
  touchData[2] = (touchData[2] * 15 + touchRead(LEVERSENSOR_L)) / 16;
  touchData[3] = (touchData[3] * 15 + touchRead(LEVERSENSOR_R)) / 16;

  // recompute estimates for mean and standard deviation in each touch line and updates thresholds accordingly
  if (touchAdjust) {
    ++sampleCnt[0];
    for (int i = 0; i < 4; i++) {
      meanTouchVals[i] = meanTouchVals[i] + ((touchData[i] - meanTouchVals[i]) / sampleCnt[0]); // update mean
    }
    if ((millis() - adjustClocker) > (touchAdjustDur / 2)) { // second part of adjustment: get summed variance
      ++sampleCnt[1];
      for (int i = 0; i < 4; i++) {
        stdTouchVals[i] = stdTouchVals[i] + sq(touchData[i] - meanTouchVals[i]); // update standard deviation (summed variance here)
      }
    }
    if ((millis() - adjustClocker) > touchAdjustDur) {  // done with adjustment
      for (int i = 0; i < 4; i++) {
        stdTouchVals[i] = sqrt(stdTouchVals[i] / sampleCnt[1]) + touchThreshOffset; // compute standard deviation from summed variance
      }
      touchAdjust = false;
    }
  }

  /////////////////////////////////////////////////////////////////////////////////////////////
  // check touch lines and create according output
  if (!touchAdjust & !spoutMoves & !leverMoves) {
    if (touchData[0] > (meanTouchVals[0] + (stdTouchVals[0]*touchThresh))) { // signal above 'stdTouchVals' standard deviations indicate lick event. only when spouts dont move.
      spoutClocker_L = millis(); //update time when spout was last touched
      if (!spoutTouch_L) {
        Serial1.write(LEFT_SPOUT_TOUCH); // send a byte to bpod if this is an onset event
      }
      spoutTouch_L = true;
    }
    else {
      if ((millis() - spoutClocker_L) >= sRateLicks) { // check when lever was last touched and set output to low if it happened too long ago.
        if (spoutTouch_L) {
          Serial1.write(LEFT_SPOUT_RELEASE); // send a byte to bpod if this is an offset event
        }
        spoutTouch_L = false;
      }
    }


    if (touchData[1] > (meanTouchVals[1] + (stdTouchVals[1]*touchThresh))) { // signal above 'stdTouchVals' standard deviations indicate lick event. only when spouts dont move.
      spoutClocker_R = millis(); //update time when spout was last touched
      if (!spoutTouch_R) {
        Serial1.write(RIGHT_SPOUT_TOUCH); // send a byte to bpod if this is an onset event
      }
      spoutTouch_R = true;
    }
    else {
      if ((millis() - spoutClocker_R) >= sRateLicks) { // check when lever was last touched and set output to low if it happened too long ago.
        if (spoutTouch_R) {
          Serial1.write(RIGHT_SPOUT_RELEASE); // send a byte to bpod if this is an offset event
        }
        spoutTouch_R = false;
      }
    }


    if (touchData[2] > (meanTouchVals[2] + (stdTouchVals[2]*touchThresh))) { // signal above 200mv from lick circuit and not receiving serial data
      touchClocker_L = millis(); //update time when lever was last touched
      if (!leverTouch_L) {
        Serial1.write(LEFT_HANDLE_TOUCH); // send a byte to bpod if this is an onset event
      }
      leverTouch_L = true;
    }
    else {
      if ((millis() - touchClocker_L) >= sRateLever) { // check when lever was last touched and set output to low if it happened too long ago.
        if (leverTouch_L) {
          Serial1.write(LEFT_HANDLE_RELEASE); // send a byte to bpod if this is an offset event
        }
        leverTouch_L = false;
      }
    }

    if (touchData[3] > (meanTouchVals[3] + (stdTouchVals[3]*touchThresh))) { // signal above 200mv from lick circuit and not receiving serial data
      touchClocker_R = millis(); //update time when lever was last touched
      if (!leverTouch_R) {
        Serial1.write(RIGHT_HANDLE_TOUCH); // send a byte to bpod if this is an onset event
      }
      leverTouch_R = true;
    }
    else {
      if ((millis() - touchClocker_R) >= sRateLever) { // check when lever was last touched and set output to low if it happened too long ago.
        if (leverTouch_R) {
          Serial1.write(RIGHT_HANDLE_RELEASE); // send a byte to bpod if this is an offset event
        }
        leverTouch_R = false;
      }
    }

    if (leverTouch_L && leverTouch_R) {
      if (!leverTouch_BOTH) {
        Serial1.write(BOTH_HANDLES_TOUCH); // send a byte to bpod if this is an onset event
      }
      leverTouch_BOTH = true;
    }
    else {
      if (((millis() - touchClocker_L) >= sRateLever) || ((millis() - touchClocker_R) >= sRateLever)) { // check when lever was last touched and set output to low if it happened too long ago.
        leverTouch_BOTH = false;
      }
    }
  }

  ////////////////////////////////////////////////////////////////////////////////////////
  // Check for ongoing spout movements
  if (spoutMoves == true) { // check spout motion
    // left spout movements
    if (lSpoutMovesIn || lSpoutMovesOut || lSpoutMovesAdjust) {
      if ((micros() - lSpoutClocker) >= lSpoutInc) { // move left spout motor
        lSpoutClocker = micros();

        // find absolute outer limits, this happens when requestion a movement to position zero
        if (findSpoutOut[0]) { // left spout is moving to zero position
          digitalWriteFast(PIN_SPOUTDIR_L, LOW_DIR_S); // make sure stepper is moving in the right direction
          delayMicroseconds(10); // short delay to ensure direction has changed
          sendStep(PIN_SPOUTSTEP_L, stepPulse); // make a step
          if (!digitalReadFast(PIN_SPOUTOUT_L)) { // check if outer limit has been reached
            findSpoutOut[0] = false;
            lServoCurrent = 0;
          }
        }

        // regular movements, relative to zero position
        if (!findSpoutOut[0]) {

          // left spout moves in
          if (lSpoutMovesIn == true) {
            // target hasnt been reached yet
            if (lServoCurrent != lServoIn) {
              lServoCurrent = moveLeftSpout(lServoCurrent, lServoIn, stepPulse); // move left spout
            }

            // stop motion when target has been reached
            if (lServoCurrent == lServoIn) {
              lSpoutMovesIn = false;
            }
          }

          // left spout adjustment movement
          else if (lSpoutMovesAdjust == true) {

            // target hasnt been reached yet
            if (lServoCurrent != lServoAdjust) {
              lServoCurrent = moveLeftSpout(lServoCurrent, lServoAdjust, stepPulse); // move left spout
            }

            // stop motion when target has been reached
            if (lServoCurrent == lServoAdjust) {
              lSpoutMovesAdjust = false;
            }
          }

          // left spout moves out
          else if (lSpoutMovesOut == true) {
            // target hasnt been reached yet
            if (lServoCurrent != lServoOut) {
              lServoCurrent = moveLeftSpout(lServoCurrent, lServoOut, stepPulse); // move left spout
            }

            // stop motion when target has been reached
            if (lServoCurrent == lServoOut) {
              lSpoutMovesOut = false;
            }
          }
        }
      }
    }


    // right spout movements
    if (rSpoutMovesIn || rSpoutMovesOut || rSpoutMovesAdjust) {
      if ((micros() - rSpoutClocker) >= rSpoutInc) { // move right spout motor
        rSpoutClocker = micros();
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

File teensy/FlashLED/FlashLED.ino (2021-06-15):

                    // Code to control a single bar matrix displays for behavioral stimulation.
// Generates a sequence of digital output signals to generate sweeping visual motion. Alternatively, the whole panel is triggered.
// Inputs are digital sequences of 0.1ms duration per pulse. Each sequence should consist of up to 5bits (0.5ms in toal).
// A single high or any unknown sequence deactivates the panel.
// A 1-0-1 signal will trigger the sequence mode where a limited number of LEDs are active. Subsequent signals, move the sequence accross the panel.
// A 1-0-1-0-1 signal will switch on the whole panel
// Made to run on Teensy 3.2
//////////////////////////////////////////////////////////////////////////////////////////////////

// define digital lines
#define IN_STIM 23 // trigger for motion sequence
#define IN_BLUE1 22 // trigger1 for ambient blue light
#define IN_BLUE2 21 // trigger2 for ambient blue light
#define OUT_BLUE 20 // output for ambient blue light

// stim variables
int lightCount = 20; // number of used LEDs for a single display (default is 20).
int barWidth = 1; // width of moving bar in LEDs
int barSpace = 4; // space between two bars in LEDs (barWidth + barSpace should be a divider of lightCount-1)
float outOffset = 0; // offset for output channels. This is the first channel that will be used for display control. The last is at outOffset + lightCount - 1.
unsigned int sigDur = 500; // duration of stim signal on 'IN_STIM' pin. Default is 500us.

// internal variables
bool newStim = true; // flag if a trigger should be read
bool switchStim = true; // flag if waiting for low signal
bool dispOn = false; // flag to indicate if display is on.
int stimInd = 0; // index for display sequence
int counter = 0; // temporary variable to count triggers.
int temp = 0; // temporary variable.
unsigned int maxOnTime = 3000; // maximum ontime without another trigger to keep curren pattern alive. Default is 1000ms.
unsigned long clocker = micros(); // timer to measure trigger signal duration

// blue light variables
unsigned int blueDur = 500; // duration of blue ambient light output after receiving a trigger. Default is 500ms.
bool blueOn = false; // flag if blue light is on
unsigned long blueClocker = millis(); // timer to measure blue light output duration
int blueThresh = 200; // threshold for analog signal to trigger blue light output
int blueCheck[2] = {0, 0};
//////////////////////////////////////////////////////////////////////////////////////////////////
int offset = 0;

void setup() {
  // set input lines
  pinMode(IN_STIM, INPUT);
  pinMode(IN_BLUE1, INPUT); // left stim lane
  pinMode(IN_BLUE2, INPUT); // right stim lane
  pinMode(OUT_BLUE, OUTPUT);

  // set up output lines
  for (int i = 0; i < lightCount; ++i) {
    pinMode(i + outOffset, OUTPUT); // output pins for LED control
  }

  for (int i = 0; i < lightCount; ++i) {
    digitalWriteFast(outOffset + i, LOW);
  }
  // for debugging
  Serial.begin(9600);
  
}


//////////////////////////////////////////////////////////////////////////////////////////////////

void loop() { // check stim trigger and control display

  if (digitalReadFast(IN_STIM) == HIGH) {  // new trigger. read signal and set state.
    Serial.println("Counting");
    switchStim = false;
    counter = 1;
    clocker = micros();

    while ((micros() - clocker) <= sigDur) { // read trigger signal for 'sigDur'. Summed up trigger events define display mode.
      if (digitalReadFast(IN_STIM) == LOW) {
        switchStim = true;
      }
      else {
        if (switchStim) {
          ++counter; // increase counter
          switchStim = false; //wait for next low before increasing counter again
        }
      }
    }
  }

  else {
    counter = 0; // reset trigger counter
  }
  if (counter>1) {
    Serial.println("count");
    Serial.println(counter);
    
  }
  if (counter == 1 || counter > 2 || ((micros() - clocker) > maxOnTime * 1000)) { // unknown trigger or stop signal. reset display if currently in motion.
    clocker = micros();
    stimInd = outOffset; // reset sequence index

    for (int i = 0; i < lightCount; ++i) {
      digitalWriteFast(outOffset + i, LOW);
    }
  }

  if (counter == 2) { // sequence mode. move bars in display.
    for (int i = 0; i < lightCount; ++i) {

      temp = stimInd + i;
      if (temp >= outOffset + lightCount)  {
        temp = temp % lightCount;
      }

      if ((i % (barWidth + barSpace)) >= barWidth) { // same as rem(i,barWidth+barSpace) >= barWidth
        digitalWriteFast(temp, LOW);
      }
      else {
        digitalWriteFast(temp, HIGH);
      }
    }

    clocker = micros();
    ++ stimInd;
  }
  if (counter == 3) { // sequence mode. move bars in display.
    Serial.println("Playing the sequence");
    
  int offsetCount = 0;
  while (digitalReadFast(IN_STIM) == LOW) {
    for (int i = 0; i < lightCount; ++i) {
      if (i <4)
        digitalWriteFast((i+offset)%lightCount, HIGH);
      else {
        digitalWriteFast((i+offset)%lightCount, LOW);
      }
    }
//    if (offsetCount%2000 == 0) {
//      ++offset;
//    }
//    ++offsetCount;
  }
  ++offset;
    for (int i = 0; i < lightCount; ++i) {
         digitalWriteFast(i, LOW);
             Serial.println("Turning off");
             Serial.println(offsetCount);
             Serial.println(offset);

    }
    clocker = micros();
    ++ stimInd;
  }

  // this part is about producing an output for ambient light. Reset clocker on trigger and make sure output is on.
  blueCheck[0] = analogRead(IN_BLUE1);
  blueCheck[1] = analogRead(IN_BLUE2);

  if (((blueCheck[0] + blueCheck[1]) >  blueThresh)) {
    blueClocker = millis();
    digitalWriteFast(OUT_BLUE, HIGH);

    if (!blueOn) {
      digitalWriteFast(OUT_BLUE, HIGH);
      blueOn = true;
    }
  }
  if (blueOn) {
    if ((millis() - blueClocker) > blueDur) {
      digitalWriteFast(OUT_BLUE, LOW);
      blueOn = false;
    }
  }
}
bool serialTrigger = false;
void serialEvent() {
  while (Serial.available()) {
    // get the new byte:
    char inChar = Serial.read();
  }
      serialTrigger = !serialTrigger;
      if (serialTrigger)
      Serial.println("Software triggered.");
}

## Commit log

2020-02-15 Added teensy code for the LEDs and unit tests for when setting up the rigs.
2020-02-21 Added pcb lib files
2020-02-21 Added led panel pcb first version.
    [led_panel.dsn, led_panel.kicad_pcb, led_panel.sch]
2020-02-21 Added sym-lib-table to led pcb
2020-02-24 Updated kicad project to be able to load it from multiple computers without conflicts.
    [led_panel.sch]
2020-02-26 Corrected LED panel pcb (teensy bug...)
    [led_panel.dsn, led_panel.kicad_pcb, led_panel.sch]
2020-03-07 Update TouchShaker.ino
    updated touchshaker to include camera trigger on pin 2
2020-03-09 Update TouchShaker.ino
    added pwm for camera timer (pin 3)
2020-03-12 Added button to zero the handles.
2020-03-13 LED panel layout before applying routing.
    [led_panel.dsn, led_panel.kicad_pcb, led_panel.sch]
2020-03-13 Routed LED panel
    [led_panel.kicad_pcb]
2020-03-13 Added LED panel gerber files (v2).
    [led_panel-B_Cu.gbl, led_panel-B_Mask.gbs, led_panel-B_SilkS.gbo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]
2020-03-14 readme for the pcb; how to generate gerber
2020-03-17 Added button to release water on both spouts. Log before starting and after running the state machine.
2020-03-17 Fixed bonsai bug, update video path check
    [TouchShaker.ino]
2020-03-18 Added I2C communication
2020-06-26 Place holder to trigger scanimage. Button to trigger widefield.
2020-07-07 working on PCB for motor controller
    [test.kicad_pcb, test.sch]
2020-07-07 small changes
    [MC_board.kicad_pcb, MC_board.sch]
2020-07-08 Added analog output RJ45 and audio amplifier symbol.
    [MC_board.kicad_pcb, MC_board.sch]
2020-07-08 Added audio amplifier footprint.
2020-07-08 Added pinout text to kicad
    [MC_board.sch]
2020-07-08 Pinout added and rj45
    [MC_board.sch]
2020-07-08 text on screw terminal
    [MC_board.sch]
2020-07-09 added screw terminal footprints
2020-07-09 added rj45 footprint
2020-07-10 ran connections and did board layout
    [MC_board 3.sch, MC_board.kicad_pcb, MC_board.sch]
2020-07-11 Filled areas on pcb for controller.
    [MC_board.kicad_pcb, MC_board.sch]
2020-07-11 Built controller pcb
    [MC_board.sch]
2020-07-11 Fixed pin flipped on 12v barrel.
2020-07-13 Added rules
    [MC_board.sch]
2020-07-13 Added kicad pcb
    [MC_board.kicad_pcb]
2020-07-14 Flipped motor controller for space, added switches
    [MC_board 3.sch, MC_board.kicad_pcb, MC_board.sch]
2020-07-14 Added text for motor wire colors
    [MC_board.kicad_pcb]
2020-07-14 Added switch footprint. Updated wiring.
    [MC_board.kicad_pcb, MC_board.sch]
2020-07-14 text for handles and spouts
    [MC_board.kicad_pcb]
2020-07-14 renamed motor controller. Cleaning up.
    [MC_board.kicad_pcb, MC_board.sch]
2020-07-14 Renamed and cleaned up rescue libs so the project is self-contained.
    [controller-B_Cu.gbl, controller-B_Mask.gbs, controller-B_SilkS.gbo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]
2020-07-15 Added split LED panel.
    [led_panel_left.kicad_pcb, led_panel_right.kicad_pcb, led_panel_split.kicad_pcb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]
2020-07-17 Adde parts for 3d design
    [01_mirror_holder_45.stl, 01_spout_steppers_holder.stl, 01_water_valves_external.stl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]
2020-07-21 I2C changes for working with the 2P. Works with the new bonsai workflow
2020-07-21 Printing names stopping the copy.
2020-07-25 2.2 holes for the set screws on the spout holder
    [02_spout_holder.stl, spout_holder.FCStd]
2020-07-25 Handle stepper set screws to 2.2, larger tickness.
    [02_handle_stepper.stl, handle_stepper.FCStd]
2020-07-25 Handle stepper reverted.
    [02_handle_holder.stl, 02_handle_stepper.stl, handle_stepper.FCStd]
2020-07-25 Updated flipped handle holder.
    [02_handle_rotated_flipped.stl, handle_stepper_flipped.FCStd]
2020-09-14 Controller pcb working version.
    [controller-B_Cu.gbl, controller-B_Mask.gbs, controller-B_SilkS.gbo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]
2020-11-24 Rolling average on touch sensors. Load cell commented on definition.
2020-12-03 Declared spouts in the defaults. Added button to reward a single spout.
2020-12-09 Teensy support for flipping the steppers with compiler defines.
    [TouchShaker.ino]
2020-12-15 Waits for motor movement. Changed communication with the teensy.
2020-12-17 reset teensy on start.
    [TouchShaker.ino]
2020-12-18 Interrupt for Serial1
2020-12-21 Unrewarded spout stays put on training. Reward button gives water. Move both spouts on HardPunish. Right spout moves on correct trials. Teensy pull required.
    [TouchShaker.ino]
2020-12-21 Print capacitance to serial port.
2021-01-06 Matlab can set teensy thresholds.
2021-01-06 Button only turns Stop after copy.
2021-01-06 Added switch to disable distractor on one of the each modality.
2021-01-06 Added switch to disable distractor for each modality independently.
2021-01-07 Valve button safe.
2022-06-06 Version used in the rig prototype.
